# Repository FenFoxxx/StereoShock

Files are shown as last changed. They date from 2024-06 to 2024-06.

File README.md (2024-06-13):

# StereoShock
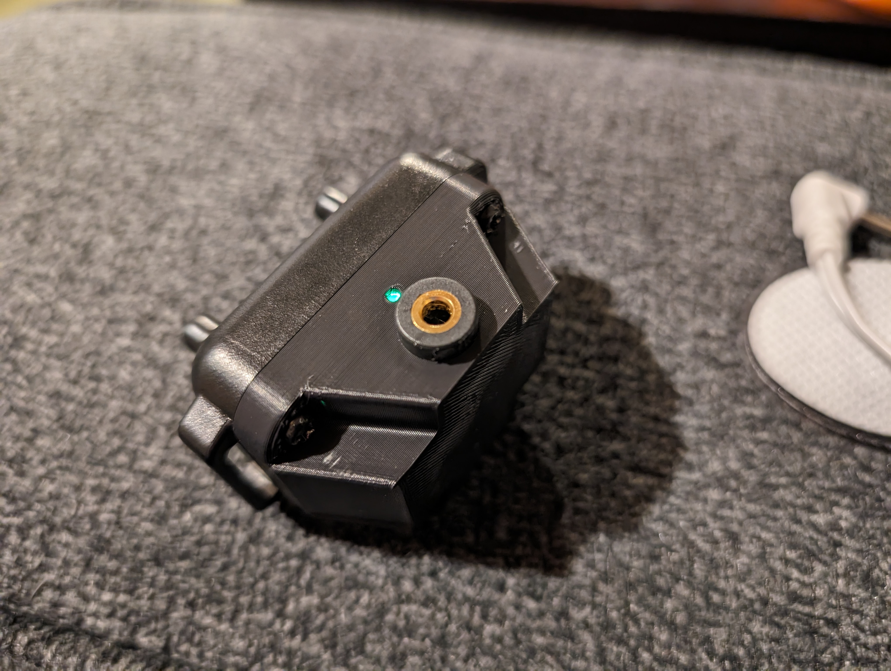
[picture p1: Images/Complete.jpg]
SteroShock Unit
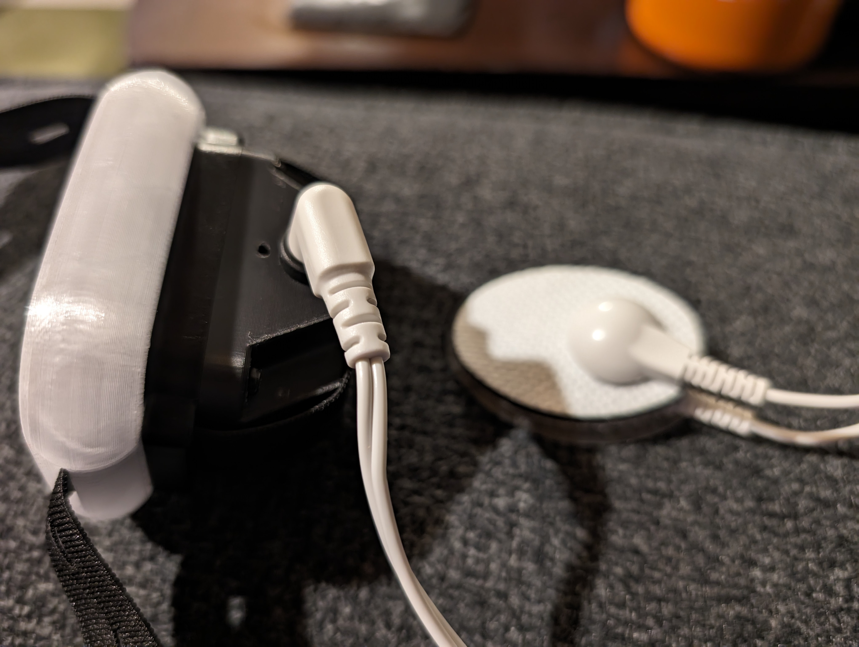
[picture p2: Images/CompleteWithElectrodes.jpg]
StereoShock with electrodes
 
## What
Stereoshock is a printed adapter for using TENS style pads with the shock collars used in the OpenShock project

## Why
The standard conductive rubber prongs on the collar are intended for use on pets, not humans. As a result, most of my testers limited the max power to 45%. With larger contact areas, you get a much wider and more controllable range of sensation, as well as being able to direct the shock into new areas where the collar wouldn't fit easily or comfortably

## How
The project consists of a 3-d printed housing for the front of the shock unit, a 3.5mm jack to insert leads, and a blanking plate to prevent the standard electrodes from making contact while wearing the collar. 

# IMPORTANT SAFETY INFO
This is provided without any warranty or guarentee of safety. Common sense applies. Do not use this device if you're sensitive to electrical impulses. Do not use with any insertable electrode. Only use pads below the waist, and never directly against the spine. The pads should never be more than an inch apart. This is not a medical device, and if you have ANY doubts about using this safely, please do not use. I am not liable for any misuse of this design or idea.

## Assembly
Instructions are in the [Assembly Guide](Docs/AssemblyInstructions.md)

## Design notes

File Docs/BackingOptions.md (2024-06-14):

# Backing Plates
There are two options for backing plates in the files, or you can make your own. You MUST have a backing plate installed if you're using the tens style electrodes. Leaving the prongs exposed gives a very good chance for an unexpected current path.

##Full Blanking Plate
This replaces the normal spacer found in the [Openshock Github](https://github.com/OpenShock/3DPrints/tree/master/LolasCollarSpacer) with one without holes for the prongs. This is the best choice if you plan to only use TENS pads.

## Spacer Blanking Plate 
This is meant to be used on top of the [normal spacer](https://github.com/OpenShock/3DPrints/tree/master/LolasCollarSpacer), allowing you to swap between the two options. A little more convienent when you just want to quickly throw the collar on, but you have to take more care to ensure your safety. 

# Above all, play safely

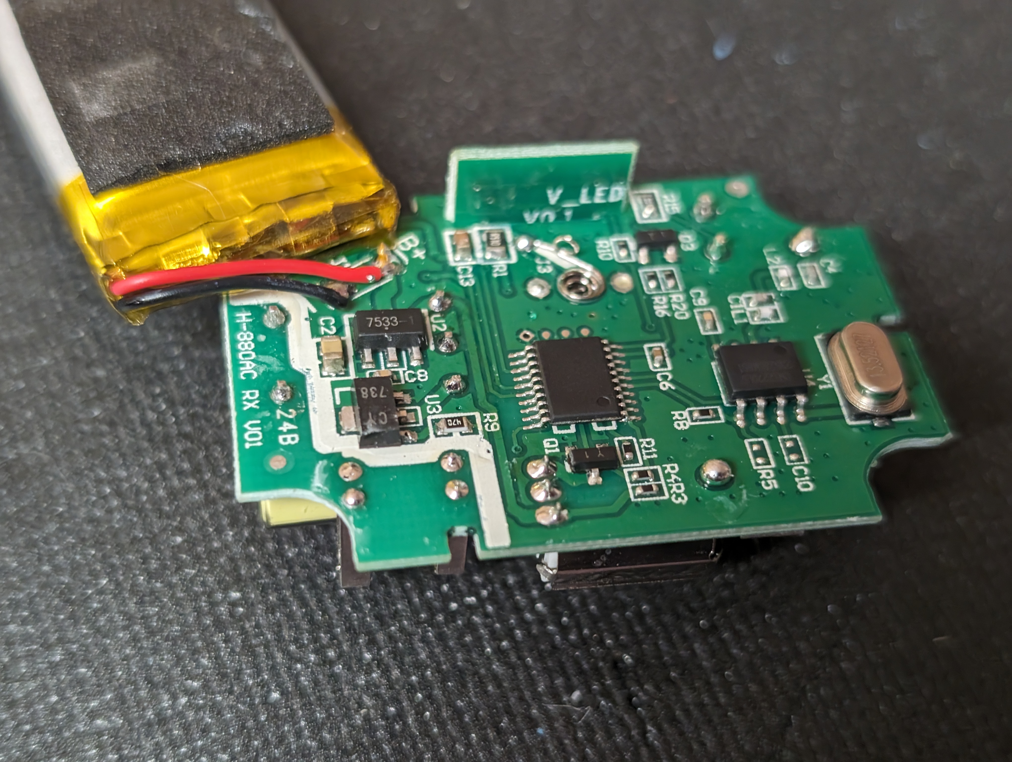
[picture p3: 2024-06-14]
Images/BatteryRemoved.jpg

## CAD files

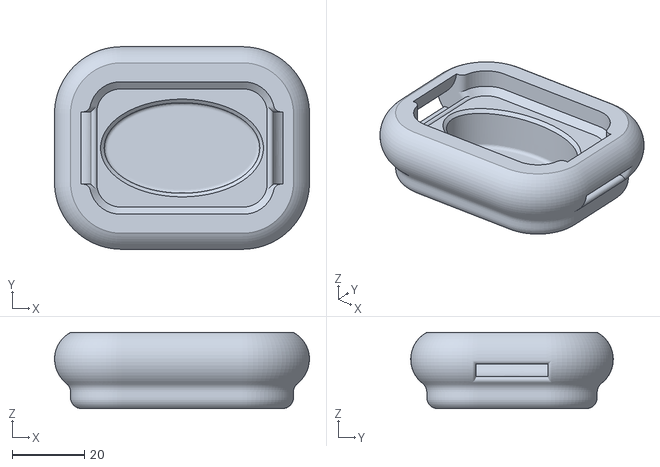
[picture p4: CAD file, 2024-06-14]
Models/FullBlankingPlate v1.stl
70.5 x 56.0 x 21.1

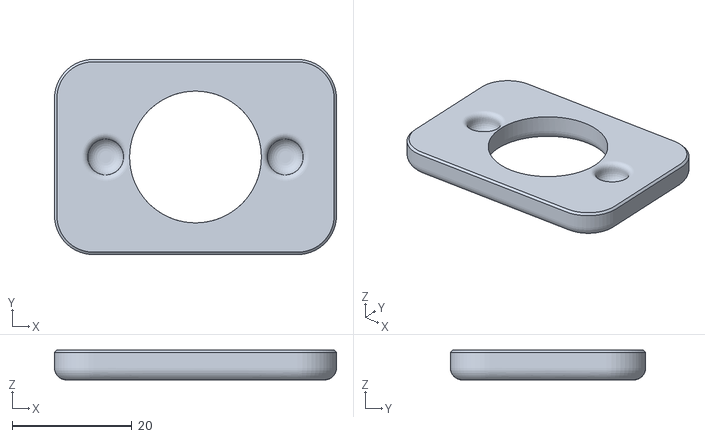
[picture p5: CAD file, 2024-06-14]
Models/SpacerBlankingPlateLarge v1.stl
47.1 x 32.6 x 5.00

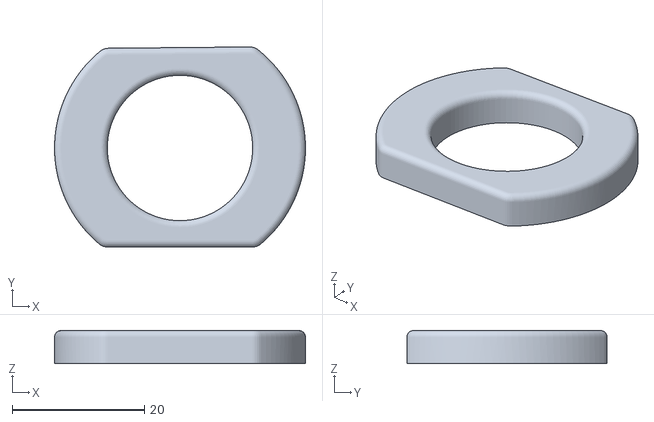
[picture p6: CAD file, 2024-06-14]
Models/SpacerBlankingPlate v1.stl
38.0 x 30.3 x 5.00

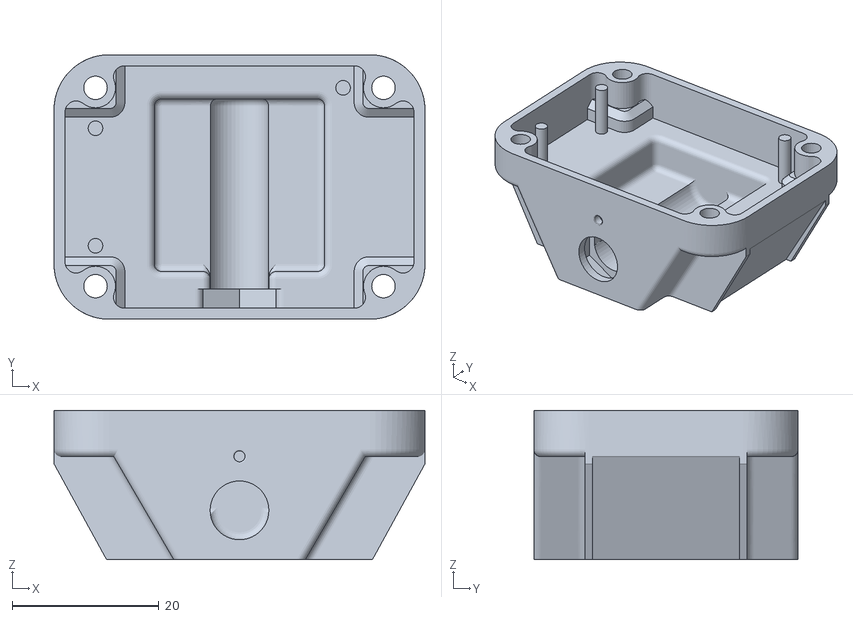
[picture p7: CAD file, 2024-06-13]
Models/ShockAdapterV13.stl
50.5 x 36.0 x 20.3

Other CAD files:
Models/CAD/FullBlankingPlate v1.f3d
Models/CAD/ShockAdapterV13.f3d
Models/CAD/SpacerBlankingPlate v1.f3d
Models/CAD/SpacerBlankingPlateLargeV1.f3z

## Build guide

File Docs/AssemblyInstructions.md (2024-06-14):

# Building the unit
Some tools and parts are required for this project:
* Soldering iron, solder, heatshrink or electrical tape
* 3d printer or printed parts
* Shock unit (CaiXianlin). See the [Openshock docs](https://openshock.org/hardware/shockers/caixianlin/) for buying guides
* Flexible wire with good insulation, I reccomend 22 gauge or better, and silicone jacketing
* 3.5mm Panel Mount Jack. I use [these](https://www.amazon.com/dp/B0C9MDDLNG?psc=1) but there are lots of identical parts
* Phillips head screwdriver
Note: Pishock units should be compatible with this mod, but the PCB landing pads are different. If you're feeling adventurous, go for it. I don't have one to experiement with

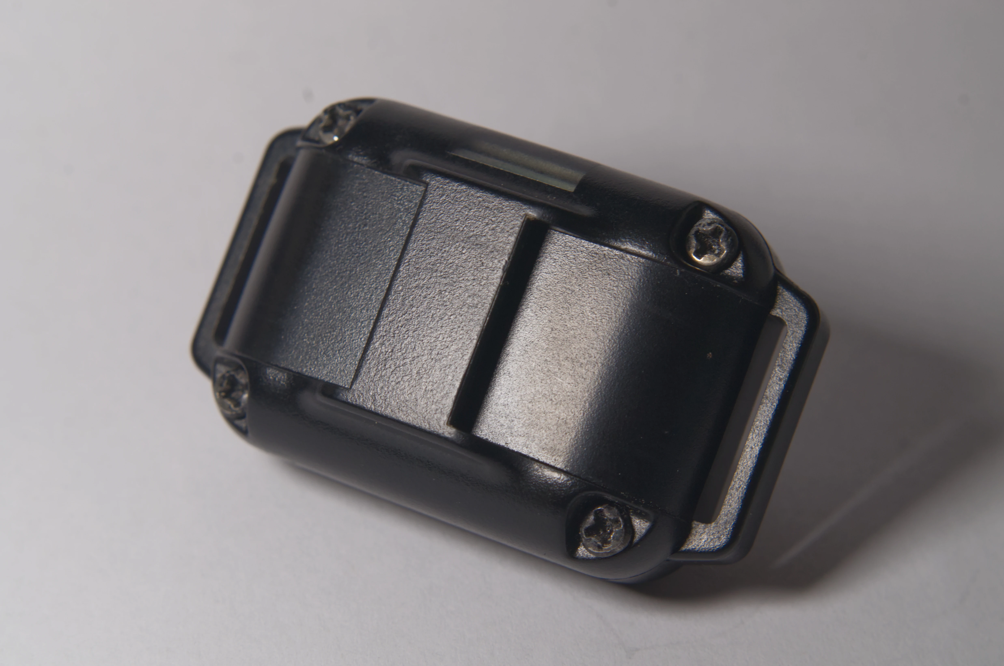
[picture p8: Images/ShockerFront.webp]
Shock Unit


## Print the Shock Adapter
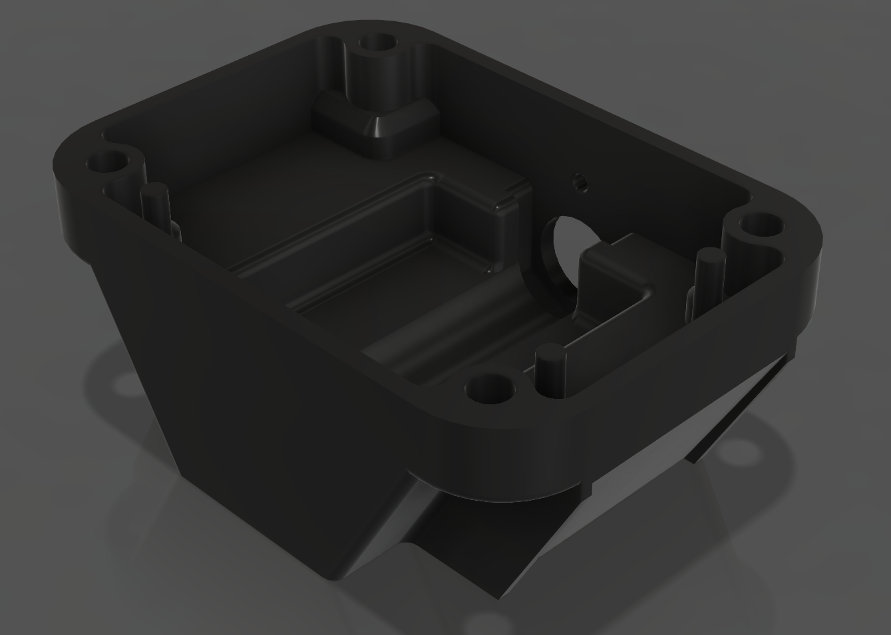
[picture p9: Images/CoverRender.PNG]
Printed Shock Adapter

The housing should be printed front down (The STL is already oriented correctly) with 0.2 layer height out of PLA or better, I use ASA. Supports are required for the flats around the screw holes, I have had good luck with PrusaSlicer's organic supports.

## Remove the front of the shocker
Cover Removed
Remove the four phillips head screws from the front of the unit. You should be able to lift the PCB out.

## Solder the jack
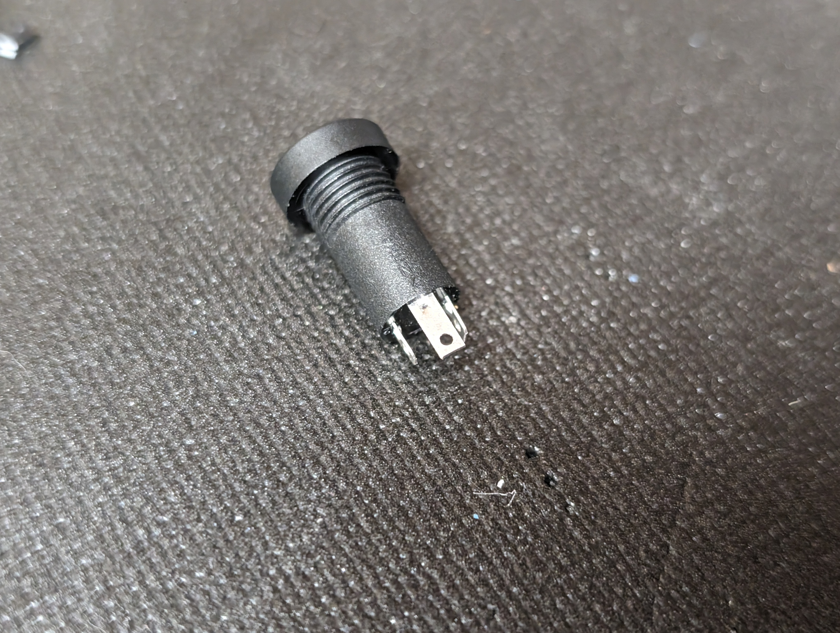
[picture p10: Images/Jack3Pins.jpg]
Jack with all 3 pins

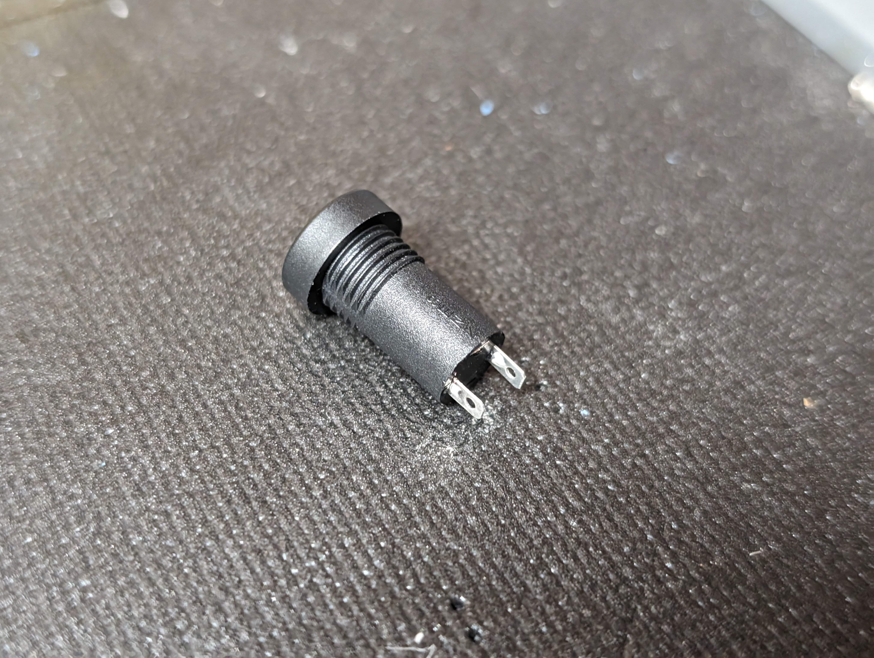
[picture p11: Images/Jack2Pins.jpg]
Spare pin removed

Locate the center (Longest pin) on the base of the jack and cut it off flush with the jack. This pin is connected to the brass ring at the top of the jack, and could provide an unexpected path for the shock if attached. 
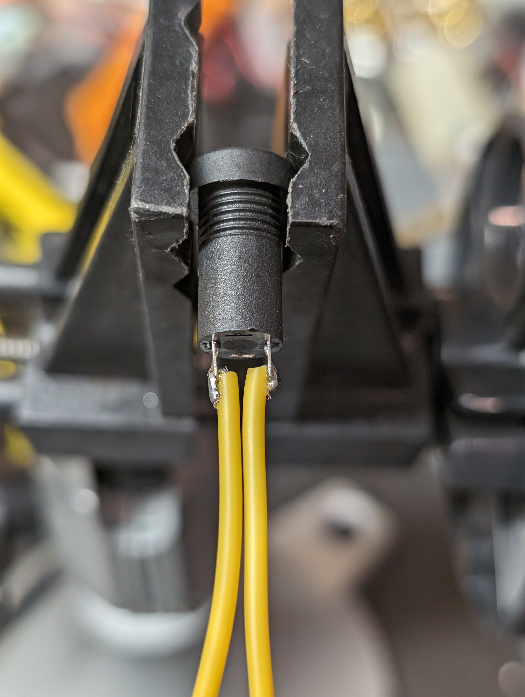
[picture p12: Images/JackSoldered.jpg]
Jack with wires soldered

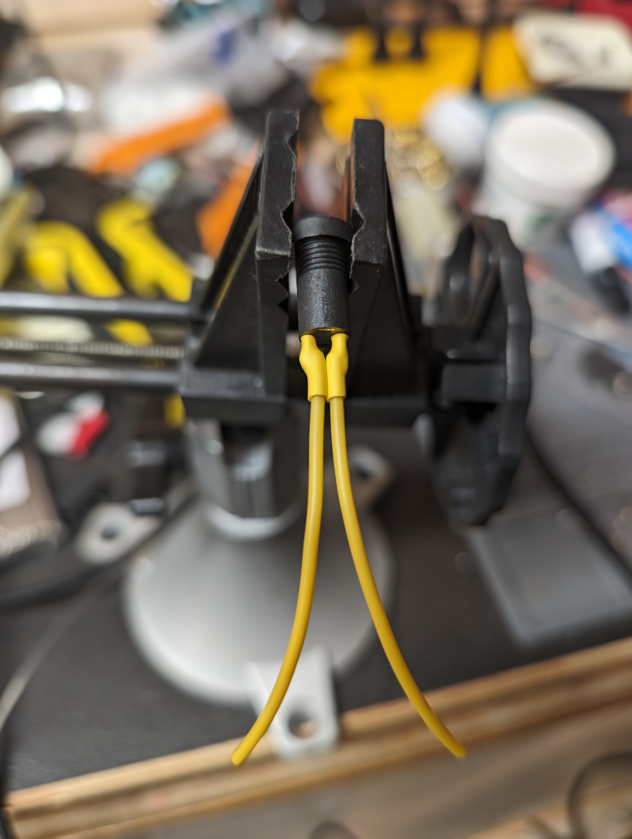
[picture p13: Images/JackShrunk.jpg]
Heatshrink applied

Solder a (roughly) 1.5 inch length of wire to each remaining terminal, and seal with heatshrink or electrical tape.

## Install the jack
Nut in housing
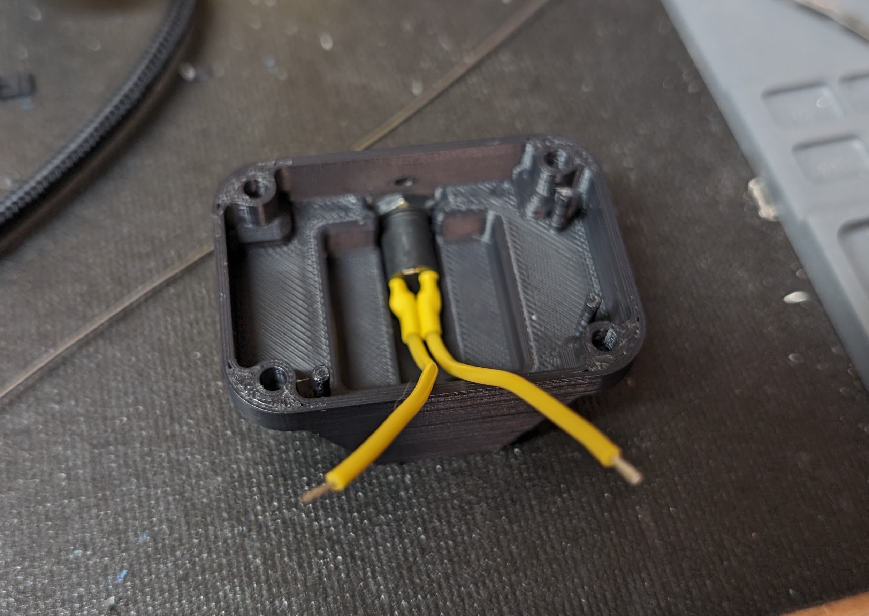
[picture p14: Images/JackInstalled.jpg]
Jack in housing

Drop the hex nut provided with the jack into the slot on the printed front plate, and then feed the wires and jack into it from the top. Tighten it into place. Hand tight is fine, or pliers to snug it down. 

## Solder to the PCB
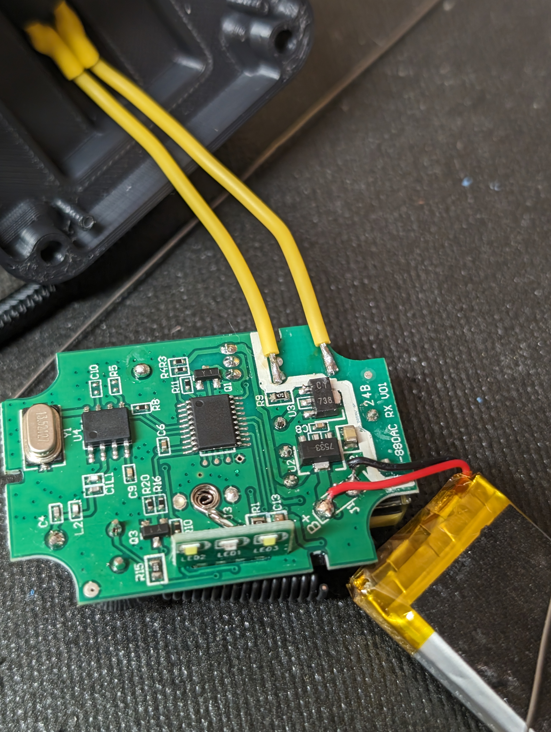
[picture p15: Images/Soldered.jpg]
Soldered to PCB

Gently rock and pull at the battery to lift it from the adhesive tape. Be careful of the power wires, and don't use a tool for this step. You don't want to puncture the battery or short out the electronics. The two paired solder pads that output to the prongs should be easy to access. Solder one wire to each pair of pads, taking care to get a good joint, and not overheating it enough to drop the metal contact off the other side. 

## Reassemble the shocker
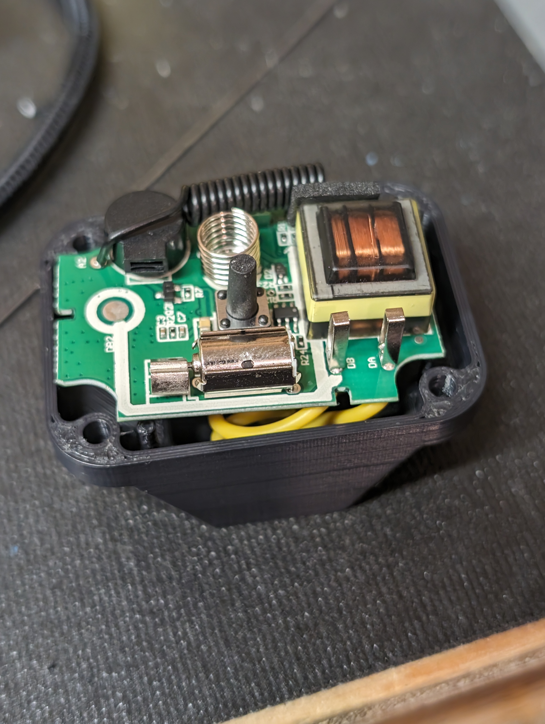
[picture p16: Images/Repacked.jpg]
Partly reassembled

Carefully press the battery back into place, and close the housing with the new front plate in place. The jack should be on the same side as the daughterboard with the LEDs, so the center LED can shine through the small hole next to the jack. The two metal prongs that extend from the PCB must be pressed against the two rubber blocks inside the back of the shell. Be careful not to pinch or damage the wires, or the battery. Reinstall the four screws. 

## Using the unit 
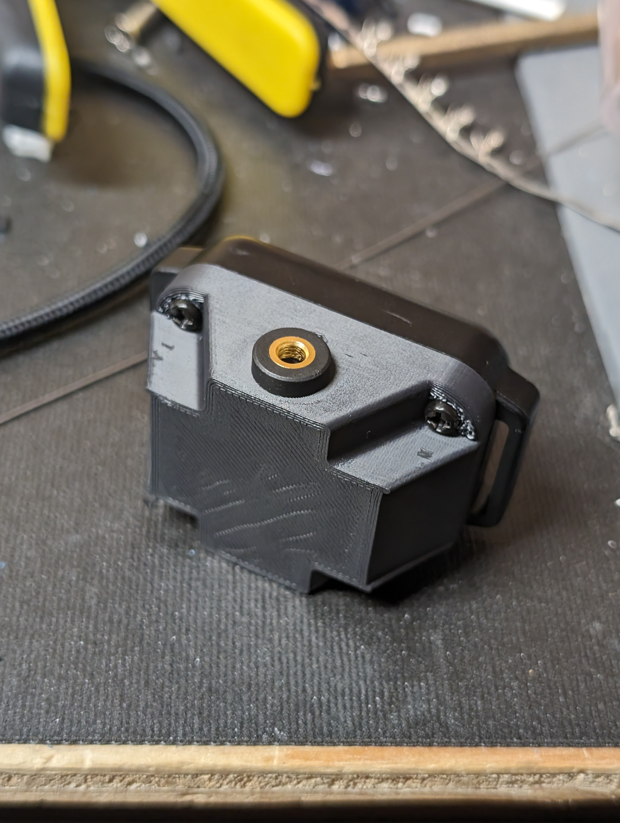
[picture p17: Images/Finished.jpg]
Finished

Congratulations! The shocker should work normally (prongs) or with your choice of TENS electrodes! When using electrodes, you MUST slide the [Backing Plate](Docs/BackingOptions.md) over the prongs. Leaving them exposed will provide unexpected and dangerous current paths. Keep the pads no more than an inch apart, and use caution with placement. Larger pads will dull the sensation, I have had the best luck with pads just about an inch in area. You can trim most pads with household scissors to adjust the sensation.

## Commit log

2024-06-13 Instructions and STLs
    First draft
    [ShockAdapterV13.f3d, ShockAdapterV13.stl]
2024-06-13 Create Assembly Instructions.md
2024-06-14 Added pics
    Pictures and fleshed out instructions
    [FullBlankingPlate v1.f3d, FullBlankingPlate v1.stl, ShockAdapterV13.f3d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]
2024-06-14 Update AssemblyInstructions.md
    Github is complicated
2024-06-14 Added more blanking plates
    [SpacerBlankingPlateLarge v1.stl, SpacerBlankingPlateLargeV1.f3z]
